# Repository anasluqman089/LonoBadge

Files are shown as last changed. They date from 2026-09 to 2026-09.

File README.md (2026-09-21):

# LonoBadge



This project is a small custom electronic badge built around the **Seeed Studio XIAO nRF52840** and a **Waveshare 1.54-inch 200×200 e-Paper display**.

The main idea is simple: connect the badge to a computer using USB-C, send a picture to it, and have the picture appear on the e-Paper display. Because the display is e-Paper, the image stays visible even after the display stops refreshing.

## BOM

* 1x Seeed Studio XIAO nRF52840
* 1x 1.54-inch 200×200 monochrome e-Paper Module
* 1 × push button
* 1x CR2032 Coin Cell Battery
* 1x CR2032 Coin Cell Battery holder

## Pin Connections

The badge uses the following pin arrangement:

```text
XIAO nRF52840       Waveshare e-Paper
--------------------------------------
D1                  CS
D2                  DC
D3                  RST
D4                  BUSY
D8                  CLK
D10                 MOSI
3V3_OUT             3.3V
GND                 GND
```

The button is connected like this:

```text
D5 ───── Push Button ───── GND
```

The firmware uses the internal pull-up resistor, so the button is normally HIGH and becomes LOW when pressed.

## How It Works

The badge communicates with the computer through the XIAO nRF52840's USB connection.

When a picture is selected on the computer, it is converted into a **200×200 black-and-white image**. The image is then sent to the XIAO through USB.

The XIAO receives the image and stores it temporarily in memory. It then sends the image to the Waveshare e-Paper display through SPI.

The basic process is:

```text
Picture on PC
     ↓
Convert to 200×200
     ↓
Convert to black & white
     ↓
USB-C
     ↓
XIAO nRF52840
     ↓
SPI
     ↓
Waveshare e-Paper
     ↓
Picture displayed
```

## Image Format

The current firmware is designed for:

Resolution: 200 × 200 pixels
Colour:     Black & White
Format:     1-bit bitmap data
Data size:  5000 bytes

## Button

The single button is connected to **D5**.

When the button is pressed, the XIAO refreshes the current image on the e-Paper display.

This can be useful if the display needs to be refreshed or if you want the button to become part of the badge's user interface later.

## Arduino Library

The firmware uses the **GxEPD2** library to control the e-Paper display.

Install the library through the Arduino IDE:

```text
Arduino IDE
    ↓
Library Manager
    ↓
Search: GxEPD2
    ↓
Install
```

The sketch also uses the standard Arduino SPI functionality.

## Uploading the Firmware

Open the `.ino` file in Arduino IDE.

Select:

```text
Board:
Seeed XIAO nRF52840
```

Then select the COM port belonging to the XIAO.

Connect the XIAO to the computer using USB-C and upload the firmware.

After the upload finishes, the e-Paper should show the startup screen and the serial monitor should report that the badge is ready.

## Sending a Picture

The firmware expects the computer to send the following header:

```text
IMG200
```

followed by exactly **5000 bytes** of image data.

A separate PC-side uploader can take a normal PNG or JPG image, resize it to 200×200, convert it to black and white, and send it to the XIAO.

For example:

```text
python upload_badge.py COM5 badge.png
```

Replace `COM5` with the COM port assigned to your XIAO.

## Current Limitations

The current version is intentionally simple.

It supports one 200×200 monochrome image at a time. The image is transferred through USB rather than making the XIAO behave like a USB flash drive.

The current button also only refreshes the image. It can be expanded later to support different images, menus, animations, or other badge functions.

The exact GxEPD2 display driver also depends on the controller used by the specific Waveshare 1.54-inch module. If the display does not initialize correctly, the exact Waveshare model should be checked before changing the wiring or firmware.

# Picture

## Schematic



## PCB



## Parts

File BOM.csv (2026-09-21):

Item | Quantity | Price | Purpose | Buy Link
Seeed Studio XIAO nRF52840 | 1 | $9.90 | Main microcontroller with native USB | https://www.seeedstudio.com/Seeed-XIAO-BLE-nRF52840-p-5201.html
1.54-inch 200x200 Monochrome e-Paper Module | 1 | $5.97 | Badge display | https://www.alibaba.com/product-detail/1-54-Inch-E-paper-Ink_1601557526526.html
Momentary Push Button | 1 | $0.049 | SW1 user input / image refresh | https://shopee.com.my/Tactile-Button-Momentary-Switch-6mm-x-6mm-x-5mm-Push-Button-4-Pin-i.1165814930.24226363215
CR2032 3V Coin Cell Battery | 1 | $1.47 | Portable power source | https://shopee.com.my/Energizer-CR2032-Coin-Batteries-2pcs-i.1790443055.46016606172
CR2032 Coin Cell Battery Holder | 1 | $0.41 | Holds and connects the coin cell | https://shopee.com.my/Battery-Holder-Wire-Snap-for-9V-CR2032-A23-A27-Batteri-i.126211897.8334686314

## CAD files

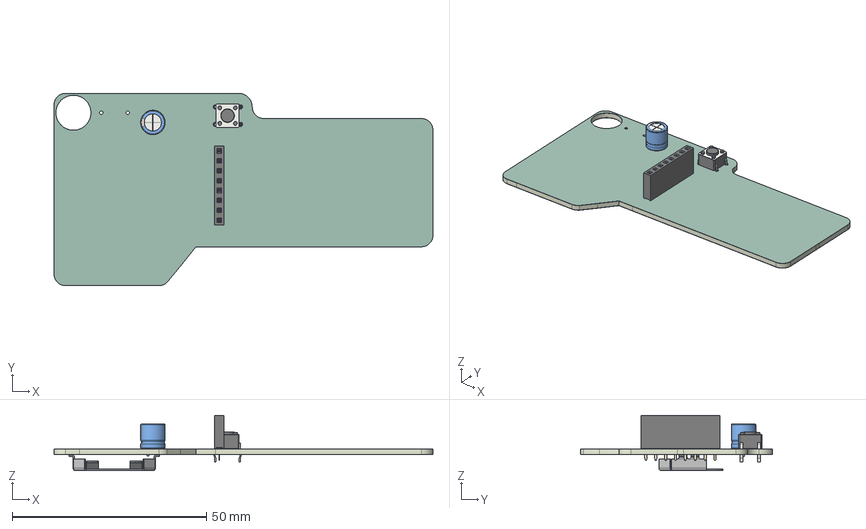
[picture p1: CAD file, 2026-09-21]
PCB/LonoBadge.step
97.5 x 49.5 x 14.2 mm
CP_Radial_D63mm_P250mm
PinSocket_1x08_P2.54mm_Vertical
SW_PUSH_6mm
BatteryHolder_Keystone_3034_1x20mm
LonA685_soldermask x 2
LonA685_PCB

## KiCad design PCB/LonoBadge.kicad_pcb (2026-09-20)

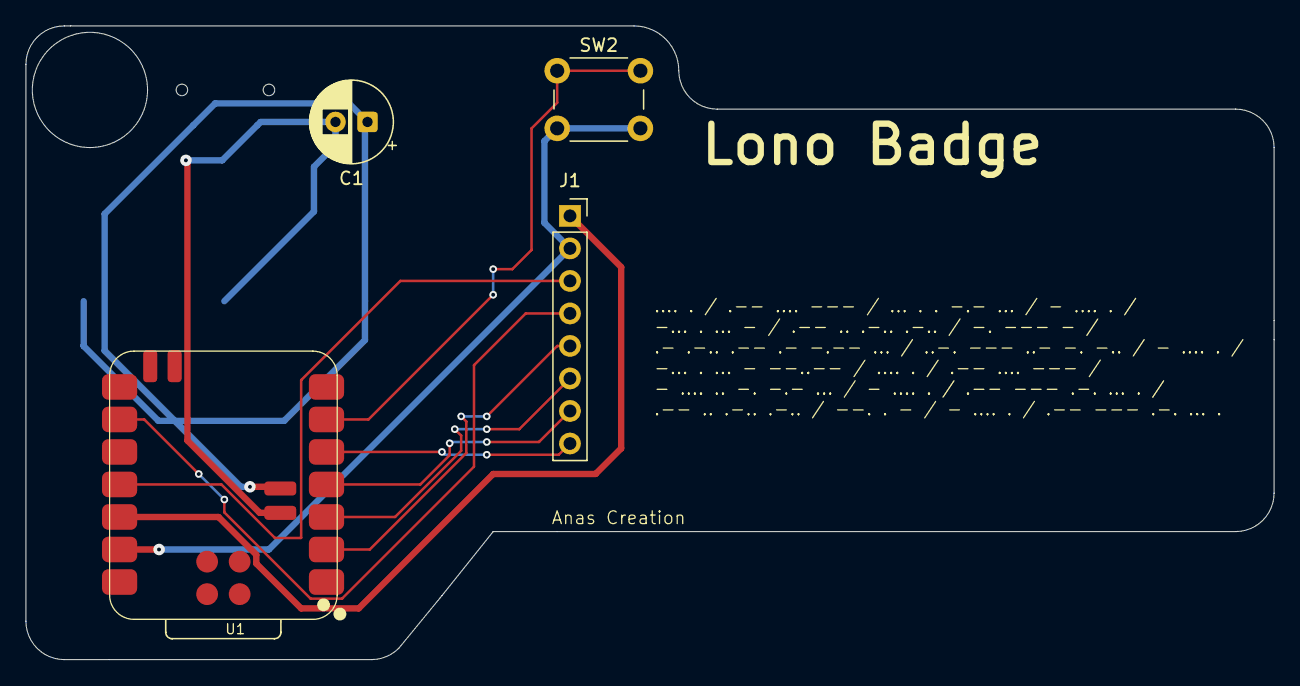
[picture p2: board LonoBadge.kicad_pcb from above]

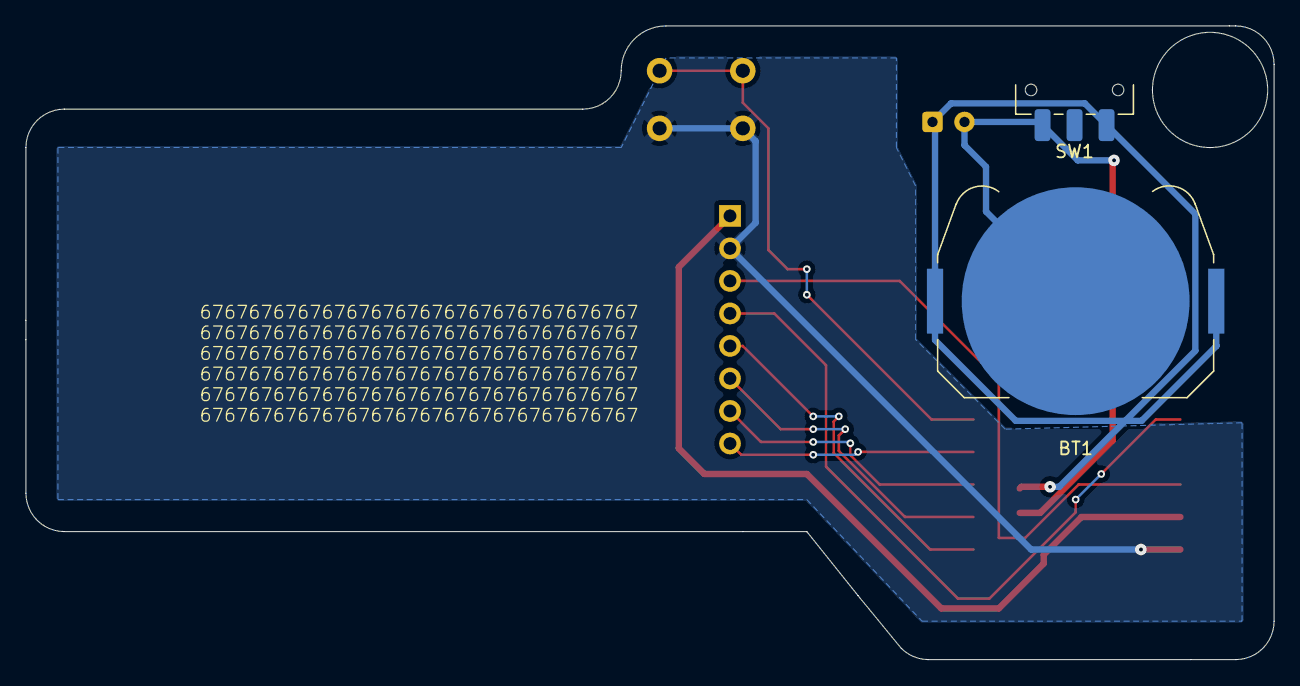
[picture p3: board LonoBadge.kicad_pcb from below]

Board: 2 copper layers, 97.5 x 49.5 mm, 6 parts (2 on the bottom side), 11 nets.

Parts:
BT1: Battery_Cell; BatteryHolder_Keystone_3034_1x20mm
C1: C; CP_Radial_D6.3mm_P2.50mm
J1: Conn_01x08_Socket; PinSocket_1x08_P2.54mm_Vertical
SW1: SW_SPDT; SW_SPDT_CK_JS102011SAQN
SW2: SW_Push; SW_PUSH_6mm
U1: XIAO-nRF52840-SMD

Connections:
+3.3V: J1.1, U1.12 (3V3_OUT)
/BSY: J1.8, U1.5 (D4)
/CLK: J1.4, U1.9 (D8)
/CS: J1.5, U1.2 (D1)
/DC: J1.6, U1.3 (D2)
/MOSI: J1.3, U1.11 (D10)
/RST: J1.7, U1.4 (D3)
/SW1: SW2.1, U1.6 (D5)
GND: J1.2, SW2.2, U1.13 (GND)
unnamed: BT1.1 (+), C1.1, SW1.1 (A), U1.19 (VBAT)
unnamed: BT1.2 (-), C1.2, SW1.3 (C), U1.20 (GND)

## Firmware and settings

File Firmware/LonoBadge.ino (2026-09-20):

#include <Arduino.h>
#include <SPI.h>
#include <GxEPD2_BW.h>

// Waveshare e-Paper
#define EPD_CS      D1
#define EPD_DC      D2
#define EPD_RST     D3
#define EPD_BUSY    D4

// User button
#define BUTTON_PIN  D5

GxEPD2_BW<
  GxEPD2_154_D67,
  GxEPD2_154_D67::HEIGHT
> display(
  GxEPD2_154_D67(
    EPD_CS,
    EPD_DC,
    EPD_RST,
    EPD_BUSY
  )
);


// IMAGE SETTINGS

#define IMAGE_WIDTH   200
#define IMAGE_HEIGHT  200

// 200 x 200 pixels / 8 bits per byte
#define IMAGE_BYTES   5000

uint8_t imageBuffer[IMAGE_BYTES];


// USB image header
const char IMAGE_HEADER[] = "IMG200\n";


// BUTTON STATE
bool previousButtonState = HIGH;


// STARTUP SCREEN
void showStartupScreen()
{
  display.setFullWindow();

  display.firstPage();

  do
  {
    display.fillScreen(GxEPD_WHITE);

    display.setTextColor(GxEPD_BLACK);

    display.setTextSize(2);
    display.setCursor(40, 80);
    display.print("BADGE");

    display.setTextSize(1);
    display.setCursor(48, 105);
    display.print("USB READY");

  }
  while (display.nextPage());
}


// FIND IMAGE HEADER
bool checkForImageHeader()
{
  static uint8_t headerIndex = 0;

  while (Serial.available())
  {
    char received = (char)Serial.read();

    if (received == IMAGE_HEADER[headerIndex])
    {
      headerIndex++;

      if (headerIndex == sizeof(IMAGE_HEADER) - 1)
      {
        headerIndex = 0;
        return true;
      }
    }
    else
    {
      headerIndex = 0;

      // Check whether this character starts a new header.
      if (received == IMAGE_HEADER[0])
      {
        headerIndex = 1;
      }
    }
  }

  return false;
}


// RECEIVE IMAGE FROM USB

bool receiveImage()
{
  uint32_t receivedBytes = 0;

  uint32_t lastDataTime = millis();

  while (receivedBytes < IMAGE_BYTES)
  {
    while (Serial.available())
    {
      int incomingByte = Serial.read();

      if (incomingByte >= 0)
      {
        imageBuffer[receivedBytes] =
          (uint8_t)incomingByte;

        receivedBytes++;

        lastDataTime = millis();
      }

      if (receivedBytes >= IMAGE_BYTES)
      {
        break;
      }
    }

    // 15-second timeout if USB transfer stops.
    if (millis() - lastDataTime > 15000)
    {
      Serial.println("ERROR:TRANSFER_TIMEOUT");
      return false;
    }

    delay(1);
  }

  Serial.println("IMAGE_RECEIVED");

  return true;
}


// DISPLAY IMAGE
void showImage()
{
  display.setFullWindow();

  display.firstPage();

  do
  {
    display.fillScreen(GxEPD_WHITE);

    for (int y = 0; y < IMAGE_HEIGHT; y++)
    {
      for (int x = 0; x < IMAGE_WIDTH; x++)
      {
        // Each byte contains 8 horizontal pixels.
        int byteIndex =
          y * (IMAGE_WIDTH / 8) +
          (x / 8);

        uint8_t bitMask =
          0x80 >> (x & 7);

        bool black =
          (imageBuffer[byteIndex] & bitMask) != 0;

        if (black)
        {
          display.drawPixel(
            x,
            y,
            GxEPD_BLACK
          );
        }
      }
    }

  }
  while (display.nextPage());

  Serial.println("DISPLAY_UPDATED");
}



// BUTTON HANDLER
void handleButton()
{
  bool currentButtonState =
    digitalRead(BUTTON_PIN);

  // Button is active LOW because it connects D5 to GND.
  if (
    previousButtonState == HIGH &&
    currentButtonState == LOW
  )
  {
    delay(30);

    // Debounce / confirm press.
    if (digitalRead(BUTTON_PIN) == LOW)
    {
      Serial.println("BUTTON_PRESSED");

      // Refresh the current image.
      showImage();

      // Wait for button release.
      while (digitalRead(BUTTON_PIN) == LOW)
      {
        delay(10);
      }
    }
  }

  previousButtonState =
    currentButtonState;
}


// SETUP
void setup()
{
  // Button connected to GND.
  pinMode(
    BUTTON_PIN,
    INPUT_PULLUP
  );

  // XIAO native USB serial.
  Serial.begin(115200);

  // Allow USB to enumerate.
  delay(1500);

  // Initialize e-Paper.
  display.init(115200);

  // Portrait orientation.
  display.setRotation(0);

  // Show startup screen.
  showStartupScreen();

  Serial.println();
  Serial.println("==============================");
  Serial.println("CUSTOM E-PAPER BADGE");
  Serial.println("==============================");

  Serial.println("BOARD: XIAO nRF52840");
  Serial.println("DISPLAY: Waveshare 1.54\"");
  Serial.println("RESOLUTION: 200x200");

  Serial.println();
  Serial.println("PIN CONFIGURATION:");
  Serial.println("CS   = D1");
  Serial.println("DC   = D2");
  Serial.println("RST  = D3");
  Serial.println("BUSY = D4");
  Serial.println("SW1  = D5");
  Serial.println("CLK  = D8");
  Serial.println("MOSI = D10");

  Serial.println();
  Serial.println("USB PROTOCOL:");
  Serial.println("IMG200 + 5000 BYTES");

  Serial.println();
  Serial.println("READY");
}


// MAIN LOOP
void loop()
{
  // Check physical button.
  handleButton();

  // Check USB for a new image.
  if (checkForImageHeader())
  {
    Serial.println("RECEIVING_IMAGE");

    if (receiveImage())
    {
      showImage();
    }
  }

  delay(2);
}

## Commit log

2026-09-20 Add file and editedthe directory
    [LonoBadge-B_Cu.gbr, LonoBadge-B_Mask.gbr, LonoBadge-B_Paste.gbr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]
2026-09-20 Enhance README with comprehensive project details
    Expanded README with detailed project description, hardware specifications, pin connections, operation process, image format, button functionality, Arduino library instructions, firmware upload steps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
2026-09-20 Rename bom (2).csv to BOM.csv
    [BOM.csv]
2026-09-21 Add price column to BOM and update item details
    Updated BOM.csv to include prices for components.
    [BOM.csv]
2026-09-21 Revise hardware section to BOM format
    Updated the hardware section to BOM format and clarified components.
2026-09-21 Updated the file directory and added .step file of PCB
    [LonoBadge-B_Cu.gbr, LonoBadge-B_Mask.gbr, LonoBadge-B_Paste.gbr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]
